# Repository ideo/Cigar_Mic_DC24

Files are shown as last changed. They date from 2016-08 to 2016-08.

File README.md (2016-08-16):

### Cigar Mic
Designed for DEF CON 24 to compliment the [Bender Badge by AND!XOR](https://github.com/ANDnXOR/ANDnXOR_DC24_Badge). The Cigar Mic adds an audio input to the Bender Badge in order to show a real-time spectrum anaysis of any activity occuring between 0 and 10kHz around the badge.

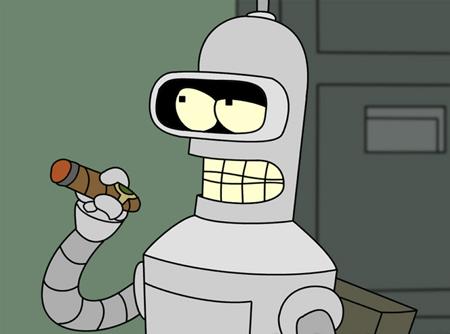
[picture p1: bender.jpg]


#### Configuration
Cigar mic requires 3.3V, GND, an ADC input pin, and three 3.3V output pins. The included software is compatible with AND!XOR’s Bender Badge and should be connected as follows:
```
OUT  -> PA1
GND  -> GND
3.3V -> 3.3V
L1   -> PA3
L2   -> PA4
L3   -> PA5
```

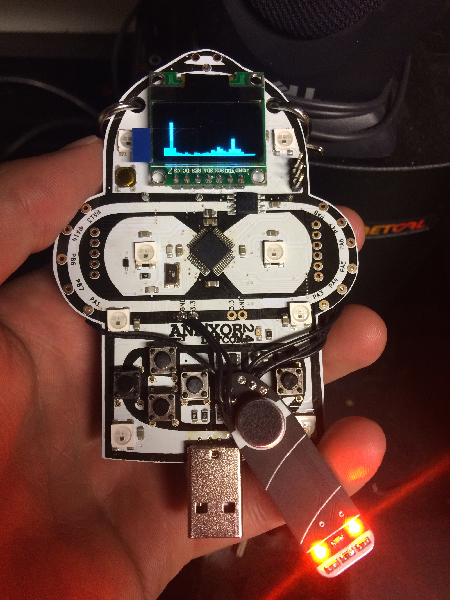
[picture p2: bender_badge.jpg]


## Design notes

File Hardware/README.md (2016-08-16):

### Cigar Mic Hardware
Schematic and layout created using [Eagle 7.4.0](https://cadsoft.io/)

The Cigar Mic is a fairly simple analog device comprised of a microphone, an amplifier, and a low pass filter. The cutoff frequency of the LPF is ~10kHz and the gain of the amplifier is 100. The circuit requires and 3.3V source, and the output signal is centered around ~1.65V.

The top side of the board includes 3 orange LEDs that run at 20mA each (this is very bright, and I’d suggest raising the value of their resistors, R7,8,9, to make the LEDs a little more subtle). These are positioned to make it look like the cigar is lit.

This layout differs slightly from what was released at DEF CON 24 in order to fix two errors with the original design. The first being the + and - flipped, hence the flywires soldered to these pins, and the other being the mic leads were flipped. Both of these were a result of quick design and not paying attention/double checking parts designed by others.

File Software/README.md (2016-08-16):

### Cigar Mic Software
This software performs a 1024-point FFT with a sampling rate of ~40kHz on analog data provided by the cigar mic to an STM32F103C series microcontroller. The audio/FFT data is then displayed on an SSD1306 (SPI) display, and three LEDs on the cigar mic are turned off or on depending on the bin levels from the FFT.

#### IDE
Software is compatible with the SMT32F103C series, and can be uploaded to a compatible microcontroller using the [Arduino 1.6.9](https://www.arduino.cc/en/Main/Software) IDE. 

Make sure the Arduino IDE is configured to work with STM32 chipsets. Details and necessary files can be found at the [Arduino STM32 project](https://github.com/rogerclarkmelbourne/Arduino_STM32).

#### Libraries
Most libraries necessary are included with the Arduino STM32 setup. The only library missing is the FFT library written by STM, and that is included in the libraries folder. Make sure you copy `libraries/stm32_cr4_fft_1024_lib` into the Arduino libraries folder.

#### To Do
* Amplitude wave mode works when uploading firmware using a serial connection, but not when uploading via bootloader.
* Windowing function needs to be further tested to make sure it’s performing correctly.
* Integrate software with AND!XOR’s Bender Badge Code. Currently the 1024-point FFT requires too much memory and therefore crashes.

#### Credits
The software for cigar mic is based on the following work:
* [Beherith’s STM32_Spectrometer](https://github.com/Beherith/STM32_Spectrometer)
* [pingumacpenguin’s STM32-O-Scope](https://github.com/pingumacpenguin/STM32-O-Scope)

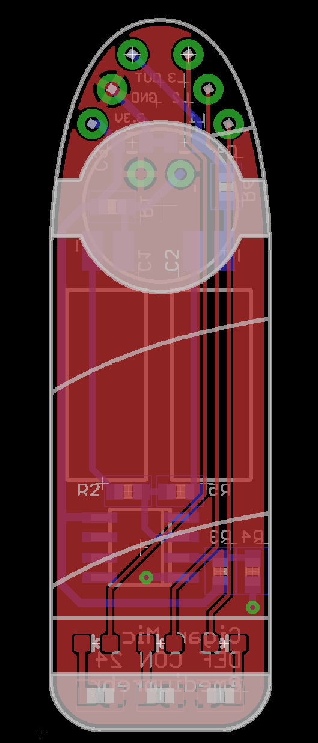
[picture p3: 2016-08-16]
Hardware/cigar_mic_layout.png

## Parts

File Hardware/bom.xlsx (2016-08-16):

Cigar Mic v1
Rob Rehr
DEF CON 24
Aug 4, 2016
Item | Reference | Package | Description | Manufacturer | Part # | Distributor | Distributor Part #
 | IC1 | 8-SO | IC OPAMP GP 1.1MHZ 8SO | STMicroelectronics | LM358DT | DigiKey | 497-1591-1-ND
 | U$1 | TH | 20Hz ~ 20kHz Analog Microphone Electret Condenser Omnidirectional (-44dB ±2dB @ 94dB SPL) PC Pins | CUI Inc | CMA-4544PF-W | DigiKey | 102-1721-ND
 | R1,3,4 | 603 | RES SMD 10K OHM 5% 1/4W 0603 | Rohm Semiconductor | ESR03EZPJ103 | DigiKey | RHM10KDCT-ND
 | R2 | 603 | RES SMD 1K OHM 5% 1/4W 0603 | Rohm Semiconductor | ESR03EZPJ102 | DigiKey | RHM1.0KDCT-ND
 | R5 | 603 | RES SMD 100K OHM 5% 1/4W 0603 | Rohm Semiconductor | ESR03EZPJ104 | DigiKey | RHM100KDCT-ND
 | R6 | 603 | RES SMD 1.5K OHM 5% 1/4W 0603 | Rohm Semiconductor | ESR03EZPJ152 | DigiKey | RHM1.5KDCT-ND
 | R7,8,9 | 603 | RES SMD 56 OHM 5% 1/4W 0603 | Rohm Semiconductor | ESR03EZPJ560 | DigiKey | RHM56DCT-ND
 | C1 | TH | 10µF 25V Aluminum Capacitors Radial, Can 1000 Hrs @ 85°C | Elna America | RFS-25V100ME3#5 | DigiKey | 604-1050-ND
 | C2 | TH | 47µF 6.3V Aluminum Capacitors Radial, Can 2000 Hrs @ 105°C | Nichicon | UKA0J470MDD1TD | DigiKey | 493-4626-1-ND
 | C3 | 805 | 0.10µF 50V Ceramic Capacitor X7R 0805 (2012 Metric) 0.079" L x 0.049" W (2.00mm x 1.25mm) | TDK Corporation | C2012X7R1H104K085AA | DigiKey | 445-7534-1-ND
 | C4 | 805 | 10000pF 250V Ceramic Capacitor JB 0805 (2012 Metric) 0.079" L x 0.049" W (2.00mm x 1.25mm) | TDK Corporation | C2012JB2E103K125AA | DigiKey | 445-11562-1-ND

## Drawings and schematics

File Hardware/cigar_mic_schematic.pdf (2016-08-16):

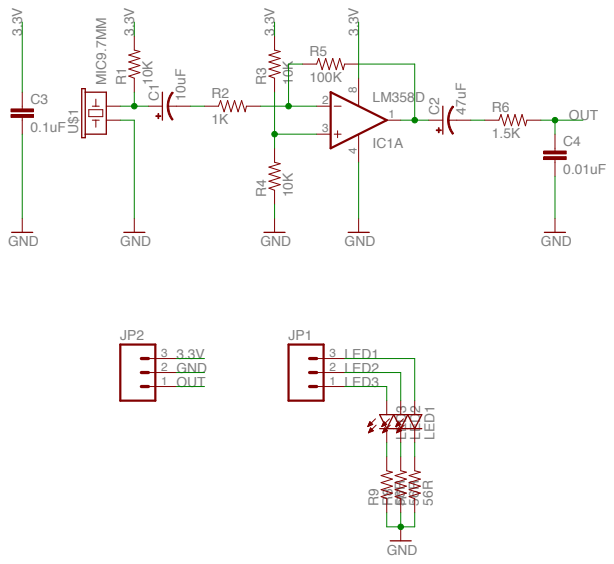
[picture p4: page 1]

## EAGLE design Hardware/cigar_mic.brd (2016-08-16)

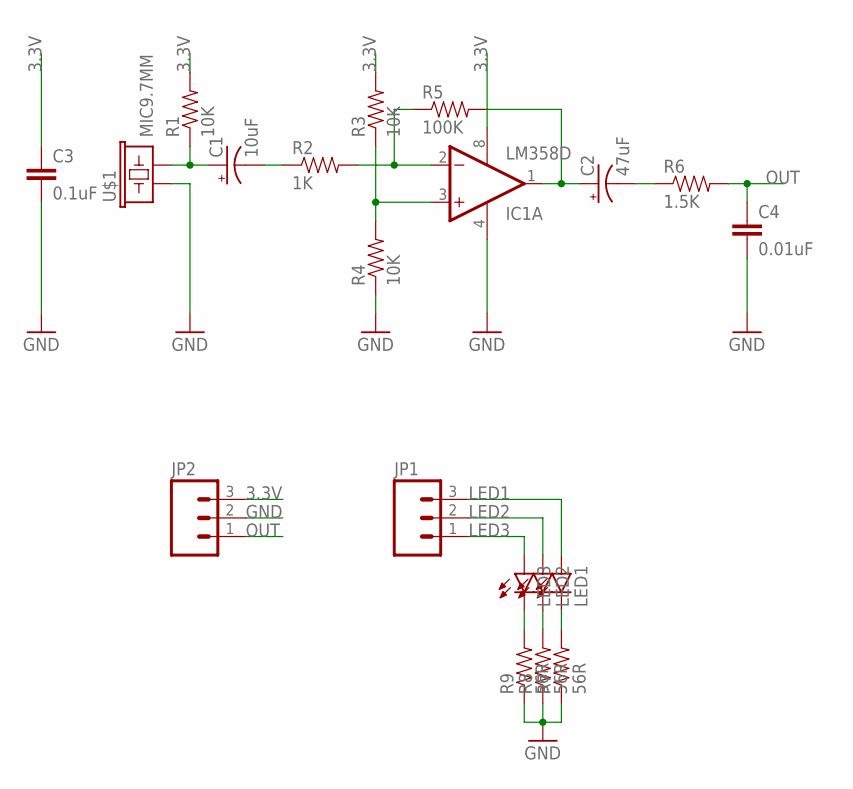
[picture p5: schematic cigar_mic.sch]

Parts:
C1: 10uF; POLAR
C2: 47uF; POLAR
C3: 0.1uF; 0805
C4: 0.01uF; 0805
IC1: LM358D; SO08
JP1, JP2: M031X03_NO_SILK; 1X03_NO_SILK
LED1, LED2, LED3: LED0603; LED-0603
R1, R3, R4: 10K; 0603-RES
R2: 1K; 0603-RES
R5: 100K; 0603-RES
R6: 1.5K; 0603-RES
R7, R8, R9: 56R; 0603-RES
U$1: MIC9.7MM; MIC-9.7MM

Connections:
3.3V: C3.1, IC1.8 (V+), JP2.3, R1.2, R3.2
GND: C3.2, C4.2, IC1.4 (V-), JP2.2, R4.1, R7.1, R8.1, R9.1, U$1.1
LED1: JP1.3, LED1.A
LED2: JP1.2, LED2.A
LED3: JP1.1, LED3.A
unnamed: C1.P$1 (+), R1.1, U$1.2
unnamed: C1.P$2 (-), R2.1
unnamed: IC1.2 (-IN), R2.2, R5.1
unnamed: IC1.3 (+IN), R3.1, R4.2
unnamed: C2.P$1 (+), IC1.1 (OUT), R5.2
unnamed: C2.P$2 (-), R6.1
unnamed: LED3.C, R9.2
unnamed: LED2.C, R8.2
unnamed: LED1.C, R7.2
OUT: C4.1, JP2.1, R6.2

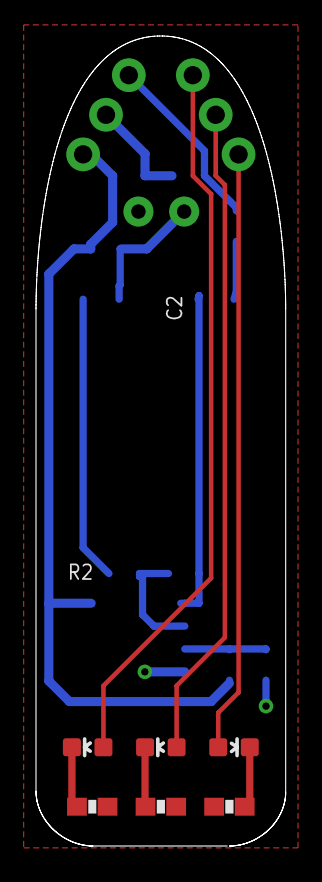
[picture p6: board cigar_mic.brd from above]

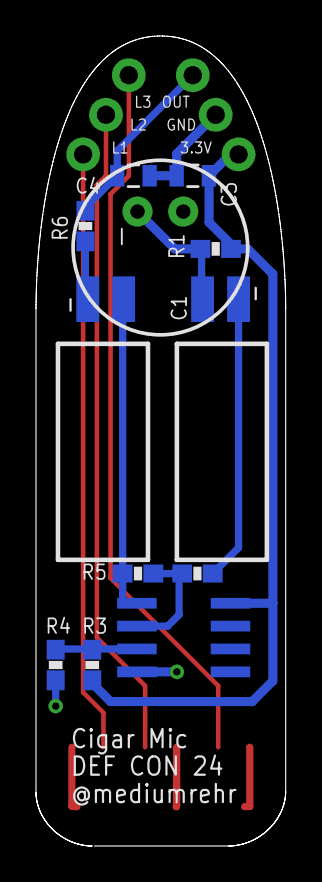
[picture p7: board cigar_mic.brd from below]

Board: 2 copper layers, 13.9 x 45.0 mm, 20 parts (12 on the bottom side), 15 nets.

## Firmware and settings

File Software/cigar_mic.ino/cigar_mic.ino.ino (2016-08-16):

////////////////////////////////////////////////////////////////////
//
//  Real-time spectrum analyzer for 0-20kHz
//   
//  Designed for DEF CON 24 and AND!XOR's Bender Badge
//
//  1024-point FFT
//  ~40kHz sampling rate
//
//  Hardware and software developed by rob rehr (@mediumrehr)
//  Last modified: Aug 16, 2016
//
//  To Do:
//  - find/fix the error with showing the audio wave in DFU mode
//  - further test windowing function
//  - integrate with AND!XOR Bender Badge code
//    - reduce SRAM usage
//
//  MIT License
//
//  Credits
//  FFT library written by STMicroelectronics
//  Software based on projects by Beherith and pingumacpenguin
//
////////////////////////////////////////////////////////////////////

//-FFT-------------------------------------------------------------------------
#define FFTLEN 1024
#define LOGSCALE 1 // display bins logarithmicallly
#define LINSCALE 0 // display bins linearly
#include <cr4_fft_1024_stm32.h>
uint16_t data16[FFTLEN];
uint32_t data32[FFTLEN];
uint32_t y[FFTLEN];
uint16_t hammingwindow[FFTLEN/2];
// my best attempt at logarithmically spacing 511 bins
uint16_t logBins[32] = {0,1,2,3,4,5,6,7,8,9,10,11,12,13,15,18,22,27,33,40,49,59,72,87,106,129,156,190,230,280,340,413};
uint16_t logBinsGap[32] = {1,1,1,1,1,1,1,1,1,1,1,1,1,2,3,4,5,6,7,9,10,13,15,19,23,27,34,40,50,60,73,98};
uint16_t FFTMode = 1; // 1 for frequecy display; 0 for amplitude display

//-Display---------------------------------------------------------------------
#include <Adafruit_GFX_AS.h>
#include <Adafruit_SSD1306_STM32.h>
#include <SPI.h>

#define SCREENWIDTH 128
#define SCREENHEIGHT 64

#define OLED_MOSI  PB15
#define OLED_CLK   PB13
#define OLED_DC    PB3
#define OLED_CS    PB12
#define OLED_RESET PB4
Adafruit_SSD1306 display(OLED_MOSI, OLED_CLK, OLED_DC, OLED_RESET, OLED_CS);

//-DMA-------------------------------------------------------------------------
volatile static bool dma1_ch1_Active;
#include <libmaple/pwr.h>
#include <libmaple/scb.h>
#include <libmaple/rcc.h>
#include <libmaple/adc.h>

//-Other-----------------------------------------------------------------------
// cigar LEDs
#define LED1 PA3
#define LED2 PA4
#define LED3 PA5
#define LEDThresh 200
const int8_t analogInPin = PA1;
uint16_t ampWave[SCREENWIDTH] = {0};

void init_hamming_window(uint16_t *windowtarget, int len) {
  for(int i=0; i<len/2; i++){ windowtarget[i] = (0.54-0.46*cos((2*i*3.141592)/(len-1)))*65536; }
}

// not certain windowing is working correctly. more testing is needed
void window(uint32_t *data, uint16_t *weights, int len, int scale) {
  for(int i=0; i<len; i++){
    int weight_index = i;
    if(i >= len/2) weight_index = (len-1)-i;
    data[i] = ((data[i]*scale*weights[weight_index]) >> 16) & 0xFFFF;
  }
}

uint16_t asqrt(uint32_t x) {
  /*   From http://medialab.freaknet.org/martin/src/sqrt/sqrt.c
   *   Logically, these are unsigned. We need the sign bit to test
   *   whether (op - res - one) underflowed.
   *   good enough precision; 10x faster than regular sqrt
   */
  int32_t op, res, one;

  op = x;
  res = 0;
  /* "one" starts at the highest power of four <= than the argument. */
  one = 1 << 30;   /* second-to-top bit set */
  while(one > op) one >>= 2;
  while(one != 0) {
    if(op >= res+one) {
      op = op-(res+one);
      res = res+2*one;
    }
    res /= 2;
    one /= 4;
  }
  return (uint16_t)(res);
}

void fill(uint32_t *data, uint32_t value, int len) {
  for(int i=0; i<len; i++) { data[i] = value; }
}

void fill(uint16_t *data, uint32_t value, int len) {
  for(int i=0; i<len; i++) { data[i] = value; }
}

void real_to_complex(uint16_t *in, uint32_t *out, int len) {
  for(int i=0; i<len; i++) { out[i] = in[i]*8; }
}

void setADCs () {
  rcc_set_prescaler(RCC_PRESCALER_ADC, RCC_ADCPRE_PCLK_DIV_8 );

  int pinMapADCin = PIN_MAP[analogInPin].adc_channel;
  adc_set_sample_rate(ADC1, ADC_SMPR_239_5); // ~37.65 khz sample rate
 
  adc_set_reg_seqlen(ADC1, 1);
  ADC1->regs->SQR3 = pinMapADCin;
  ADC1->regs->CR2 |= ADC_CR2_CONT; // set continuous mode
  ADC1->regs->CR2 |= ADC_CR2_SWSTART; // regular channels
}

static void DMA1_CH1_Event() {
  dma1_ch1_Active = 0;
}

void adc_dma_enable(const adc_dev *dev) {
  bb_peri_set_bit(&dev->regs->CR2, ADC_CR2_DMA_BIT, 1);
}

void takeSamples() {
  if(FFTMode) {
    // perform DMA, 
    dma_init(DMA1);
    dma_attach_interrupt(DMA1, DMA_CH1, DMA1_CH1_Event);

    adc_dma_enable(ADC1);
    dma_setup_transfer(DMA1, DMA_CH1, &ADC1->regs->DR, DMA_SIZE_16BITS, data16, DMA_SIZE_16BITS, (DMA_MINC_MODE | DMA_TRNS_CMPLT)); // receive buffer DMA
    dma_set_num_transfers(DMA1, DMA_CH1, FFTLEN);
    dma1_ch1_Active = 1;
  
    dma_enable(DMA1, DMA_CH1); // enable the channel and start the transfer.
    uint32_t time_left_in_dma = micros();
  
    while(dma1_ch1_Active){ }; // wait for the DMA to complete
    dma_disable(DMA1, DMA_CH1); // end of trasfer, disable DMA and continuous mode.
    real_to_complex(data16, data32, FFTLEN);
    perform_fft(data32, y, FFTLEN);
    displayBins(y, FFTLEN, LOGSCALE);
  } else {
    // only works for serial upload. doesn't work with DFU mode for some reason
    int analogIn = analogRead(analogInPin);
    displayWave(analogIn);
  }
}

void setup() {
  // enable Serial
  Serial.begin(115200); // only works with serial upload mode
  
  // initialize the display
  display.begin(SSD1306_SWITCHCAPVCC);
  display.clearDisplay();
  display.display();

  // initialize FFT variables
  init_hamming_window(hammingwindow, FFTLEN);
  fill(y,0,FFTLEN);
  fill(data32,1,FFTLEN);
  fill(data16,1,FFTLEN);

  // calibrate and setup ADC
  adc_calibrate(ADC1);
  setADCs();

  // initialize cigar LEDs
  pinMode(LED1, OUTPUT);
  pinMode(LED2, OUTPUT);
  pinMode(LED3, OUTPUT);
  digitalWrite(LED1, LOW);
  digitalWrite(LED2, LOW);
  digitalWrite(LED3, LOW);
}

void inplace_magnitude(uint32_t *target, uint16_t len){
  uint16_t * p16;
  for(int i=0; i<len; i++){
     int16_t real = target[i] & 0xFFFF;
     int16_t imag = target[i] >> 16;
     uint32_t magnitude = asqrt(real*real + imag*imag);
     target[i] = magnitude; 
  }
}
  
uint32_t perform_fft(uint32_t *indata, uint32_t *outdata, const int len){
	uint32_t timetaken = micros();
//	window(indata,hammingwindow,len,1); //scaling factor of 4 for 4095> 16 bits
	cr4_fft_1024_stm32(outdata, indata, len);
	inplace_magnitude(outdata, len);
	return micros() - timetaken;
}

// dispaly audio as an amplitude wave
// only works with serial upload mode
void displayWave(uint16_t newAnalog) {
  display.clearDisplay();
  // move previous amplitudes forward
  for(int i=(SCREENWIDTH-1); i>0; i--) {
    display.drawLine(i, (32-ampWave[i-1]), i, (32+ampWave[i-1]), WHITE);
    ampWave[i] = ampWave[i-1];
  }
  // append newest applitude
  int newAmp = newAnalog*SCREENHEIGHT/4096;
  newAmp -= 32;
  display.drawLine(0, 32-newAmp, 0, 32+newAmp, WHITE);
  ampWave[0] = newAmp;
  display.display();
}

// display audio as bin levels after FFT
void displayBins(uint32_t *data, int len, bool scale) {
  uint32_t maxvalue = 1024;
  uint32_t myBins[32] = {0};
  uint32_t LED1Max = 0;
  uint32_t LED2Max = 0;
  uint32_t LED3Max = 0;
  if(scale) {
    // logarithmic x axis
    for(int i=0; i<32; i++) {
      myBins[i] = 0;
      for(int j=0; j<logBinsGap[i]; j++) {
        int newData = data[logBins[i]+j];
        myBins[i] = max(myBins[i], newData);
      }
    }
  } else {
    // linear x axis
    for(int i=0; i<32; i++) {
      myBins[i] = 0;
      for(int j=0; j<16; j++) {
        myBins[i] = max(myBins[i], data[(i*32)+j]);
      }
    }
  }
  display.clearDisplay();
  // we toss the first bin since it's 0Hz
  for(int i=1; i< 32; i++) {
    float FFTBarHeight = myBins[i]*SCREENHEIGHT/maxvalue;
    int startXPos = 4*(31-i);
    display.drawLine(startXPos+0, 0, startXPos+0, (int)FFTBarHeight, WHITE);
    display.drawLine(startXPos+1, 0, startXPos+1, (int)FFTBarHeight, WHITE);
    display.drawLine(startXPos+2, 0, startXPos+2, (int)FFTBarHeight, WHITE);
    display.drawLine(startXPos+3, 0, startXPos+3, (int)FFTBarHeight, WHITE);

    if(i < 11) {
      if(LED1Max < myBins[i]) LED1Max = myBins[i];
    } else {
      if(i < 21) {
        if(LED2Max < myBins[i]) LED2Max = myBins[i];
      } else {
        if(LED3Max < myBins[i]) LED3Max = myBins[i];
      }
    }
  }
  
  display.display();

  // turn cigar LEDs on/off depending on bin levels
  if(LED1Max > LEDThresh) {
    digitalWrite(LED1, HIGH);
  } else {
    digitalWrite(LED1, LOW);
  }
  if(LED2Max > LEDThresh) {
    digitalWrite(LED2, HIGH);
  } else {
    digitalWrite(LED2, LOW);
  }
  if(LED3Max > LEDThresh) {
    digitalWrite(LED3, HIGH);
  } else {
    digitalWrite(LED3, LOW);
  }
}

void loop() { 
  while(1){ // loop seems to run only once, hence the while 
	  takeSamples();
  }
}

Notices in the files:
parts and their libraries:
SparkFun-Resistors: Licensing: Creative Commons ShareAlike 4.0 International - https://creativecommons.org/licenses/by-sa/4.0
